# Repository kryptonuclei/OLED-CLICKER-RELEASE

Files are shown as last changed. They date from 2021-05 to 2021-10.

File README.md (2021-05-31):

# OLED-Clicker

This creation is designed to both be a fidget item while also being able to serve a purpose. It is an electronic counter and a fidget clicker utilizing mechanical keyboard switches. The OLED used is 1.3in across, larger than the typical horizontal OLEDs. The processor is an ATMEGA32U4, from an arduino leonardo framework. The code was developed in visual studio using arduino libraries. It is powered by an 18650 that is charged via a USB C connector. The 5V rail is connected to a TP4056 to handle the charging. The 32U4 is also connected to the USB C for programming.

A sleep mode is enabled after 1 minute of inactivity, during this mode, the clicker only draws 0.4mA, almost a year standby using a 3000mAh 18650!

There are some things that would be cool to integrate but have not been completed such as https://github.com/AlexIII/t-rex-duino and a selection of menus rather than the current mode toggles. The dino game has not yet been successfully integrated as it uses drivers which are written as part of the project, but this project uses an OLED that addresses with rows and columns swapped ie 64x128 rather than standard 128x64.

# Pictures



137523917_1570962459765296_4746547366832083114_n

# Model



# PCB




# Components

Link to OLED: https://www.aliexpress.com/item/1648493376.html?spm=a2g0s.9042311.0.0.50434c4dDTX8kw

| Part  | Value | Device | Description |
| ----- | --- | --- | --- |
| BT1 | | BATTERY-18650-Holder | Battery - Single Cell |
| C1 | 1u | C-EUC0603 | CAPACITOR, European symbol |
| C2 | 100n | C-EUC0603 | CAPACITOR, European symbol |
| C3 | 22p | C-EUC0603 | CAPACITOR, European symbol |
| C4 | 22p | C-EUC0603 | CAPACITOR, European symbol |
| C5 | 2.2u | C-EUC0603 | CAPACITOR, European symbol |
| C6 | 0.1u | C-EUC0603 | CAPACITOR, European symbol |
| C7 | 4.7u | C-EUC0603 | CAPACITOR, European symbol |
| C8 | 0.1u | C-EUC0603 | CAPACITOR, European symbol |
| C9 | 4.7u | C-EUC0603 | CAPACITOR, European symbol |
| C10 | 10u | C-EUC0805 | CAPACITOR, European symbol |
| C11 | 0.1u | C-EUC0603 | CAPACITOR, European symbol |
| C12 | 0.1u | C-EUC0603 | CAPACITOR, European symbol |
| C13 | 4.7p | C-EUC0603 | CAPACITOR, European symbol |
| C14 | 0.1u | C-EUC0603 | CAPACITOR, European symbol |
| D1 | | LED0603 | LED (Generic) |
| D2 | | LED0603 | LED (Generic) |
| D4 | | LED0603 | LED (Generic) |
| D5 | | LED0603 | LED (Generic) |
| D6 | | DIODE\_SOD-123FL | Diode |
| IC1 | DW01A | DW01A | Battery Protection |
| IC2 | TP4056 | TP4056 | Battery Charger |
| J1 | DX07S016JA1R1500 | DX07S016JA1R1500 | USB-C (USB TYPE-C) USB 2.0 Receptacle Connector 24 (16+8 Dummy) Position Surface Mount, Right Angle; Through Hole  |
| L1 | | L-EUL3225M | INDUCTOR, European symbol |
| OLED1 | ADAFRUIT\_DISPLAY\_OLED\_128X64\_SH1107 | ADAFRUIT\_DISPLAY\_OLED\_128X64\_SH1107 | Horizontal ribbon 1.3in OLED |
| Q1 | FS8205A | FS8205A | MOSFET |
| R1 | 22 | R-EU\_R0603 | RESISTOR, European symbol |
| R2 | 22 | R-EU\_R0603 | RESISTOR, European symbol |
| R3 | 10k | R-EU\_R0603 | RESISTOR, European symbol |
| R4 | 330 | R-EU\_R0603 | RESISTOR, European symbol |
| R5 | 330 | R-EU\_R0603 | RESISTOR, European symbol |
| R6 | 560k | R-EU\_R0603 | RESISTOR, European symbol |
| R7 | 4.7k | R-EU\_R0603 | RESISTOR, European symbol |
| R8 | 1k | R-EU\_R0603 | RESISTOR, European symbol |
| R9 | 1k | R-EU\_R0603 | RESISTOR, European symbol |
| R10 | 1k | R-EU\_R0603 | RESISTOR, European symbol |
| R11 | 1k | R-EU\_R0603 | RESISTOR, European symbol |
| R12 | 100 | R-EU\_R0603 | RESISTOR, European symbol |
| R13 | 4.7k | R-EU\_R0603 | RESISTOR, European symbol |
| R14 | 4.7k | R-EU\_R0603 | RESISTOR, European symbol |
| R15 | 1.43m | R-EU\_R0603 | RESISTOR, European symbol |
| R16 | 205k | R-EU\_R0603 | RESISTOR, European symbol |
| U$1 | ATMEGA32U4QFN2 | ATMEGA32U4QFN2 | Atmel 44-pin 8-bit Microcontroller with 32KBytes of ISP Flash and USB Controller ----- |
| U$2 | CHERRY-MX | CHERRY-MX | Cherry MX series keyswitch |
| U1 | TPS61040DBVR | TPS61040DBVR | Boost IC |
| Y1 | 16MHz | CRYSTAL-16MHZSMD-5X3.2 | 16MHz Crystal |

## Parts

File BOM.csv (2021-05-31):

Part | Value | Device | Package | Description
BT1 |  | BATTERY-18650 | BATTERY_18650-HOLDER | Battery - Single Cell
C1 | 1u | C-EUC0603 | C0603 | CAPACITOR, European symbol
C2 | 100n | C-EUC0603 | C0603 | CAPACITOR, European symbol
C3 | 22p | C-EUC0603 | C0603 | CAPACITOR, European symbol
C4 | 22p | C-EUC0603 | C0603 | CAPACITOR, European symbol
C5 | 2.2 | C-EUC0603 | C0603 | CAPACITOR, European symbol
C6 | 0.1 | C-EUC0603 | C0603 | CAPACITOR, European symbol
C7 | 4.7 | C-EUC0603 | C0603 | CAPACITOR, European symbol
C8 | 0.1 | C-EUC0603 | C0603 | CAPACITOR, European symbol
C9 | 4.7 | C-EUC0603 | C0603 | CAPACITOR, European symbol
C10 | 10u | C-EUC0805 | C0805 | CAPACITOR, European symbol
C11 | 0.1 | C-EUC0603 | C0603 | CAPACITOR, European symbol
C12 | 0.1 | C-EUC0603 | C0603 | CAPACITOR, European symbol
C13 | 4.7p | C-EUC0603 | C0603 | CAPACITOR, European symbol
C14 | 0.1u | C-EUC0603 | C0603 | CAPACITOR, European symbol
D1 |  | LED0603 | LED-0603 | LED (Generic)
D2 |  | LED0603 | LED-0603 | LED (Generic)
D4 |  | LED0603 | LED-0603 | LED (Generic)
D5 |  | LED0603 | LED-0603 | LED (Generic)
D6 |  | DIODE_SOD-123FL | SOD-123FL | Diode
IC1 | DW01A | DW01A | SOT23-6
IC2 | TP4056 | TP4056 | SOP-8
J1 | DX07S016JA1R1500 | DX07S016JA1R1500 | JAE_DX07S016JA1R1500 | USB-C (USB TYPE-C) USB 2.0 Receptacle Connector 24 (16+8 Dummy) Position Surface Mount, Right Angle; Through Hole Check prices
L1 |  | L-EUL3225M | L3225M | INDUCTOR, European symbol
OLED1 | ADAFRUIT_DISPLAY_OLED_128X64_SH1107 | ADAFRUIT_DISPLAY_OLED_128X64_SH1107 | ADAFRUIT_DISPLAY_QT1107P11A
PAD1 |  | SMD5 | SMD2,54-5,08 | SMD PAD
PAD2 |  | SMD5 | SMD2,54-5,08 | SMD PAD
PAD3 |  | SMD5 | SMD2,54-5,08 | SMD PAD
PAD4 |  | SMD5 | SMD2,54-5,08 | SMD PAD
Q1 | FS8205A | FS8205A | SOP65P640X120-8N | N/A
R1 | 22 | R-EU_R0603 | R0603 | RESISTOR, European symbol
R2 | 22 | R-EU_R0603 | R0603 | RESISTOR, European symbol
R3 | 10k | R-EU_R0603 | R0603 | RESISTOR, European symbol
R4 | 330 | R-EU_R0603 | R0603 | RESISTOR, European symbol
R5 | 330 | R-EU_R0603 | R0603 | RESISTOR, European symbol
R6 | 560k | R-EU_R0603 | R0603 | RESISTOR, European symbol
R7 | 4.7k | R-EU_R0603 | R0603 | RESISTOR, European symbol
R8 | 1k | R-EU_R0603 | R0603 | RESISTOR, European symbol
R9 | 1k | R-EU_R0603 | R0603 | RESISTOR, European symbol
R10 | 1k | R-EU_R0603 | R0603 | RESISTOR, European symbol
R11 | 1k | R-EU_R0603 | R0603 | RESISTOR, European symbol
R12 | 100 | R-EU_R0603 | R0603 | RESISTOR, European symbol
R13 | 4.7k | R-EU_R0603 | R0603 | RESISTOR, European symbol
R14 | 4.7k | R-EU_R0603 | R0603 | RESISTOR, European symbol
R15 | 1.43m | R-EU_R0603 | R0603 | RESISTOR, European symbol
R16 | 205k | R-EU_R0603 | R0603 | RESISTOR, European symbol
U$1 | ATMEGA32U4QFN2 | ATMEGA32U4QFN2 | SPARKFUN-DIGITALIC_QFN-44-NOPAD | Atmel 44-pin 8-bit Microcontroller with 32KBytes of ISP Flash and USB Controller -----
U$2 | CHERRY-MX | CHERRY-MX | CHERRY-MX | Cherry MX series keyswitch
U1 | TPS61040DBVR | TPS61040DBVR | SOT95P280X145-5N | Check prices
Y1 | 16MHz | CRYSTAL-16MHZSMD-5X3.2 | CRYSTAL-SMD-5X3.2-4PAD | 16MHz Crystal

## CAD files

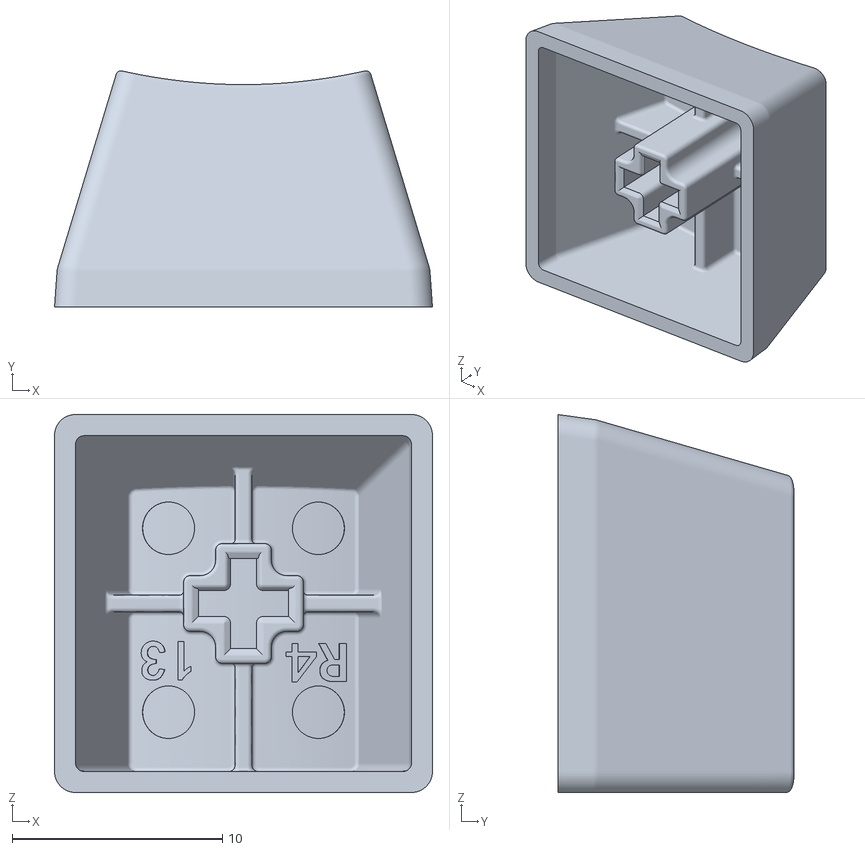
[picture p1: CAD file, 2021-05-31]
STL/keycap.stl
18.0 x 11.3 x 18.0

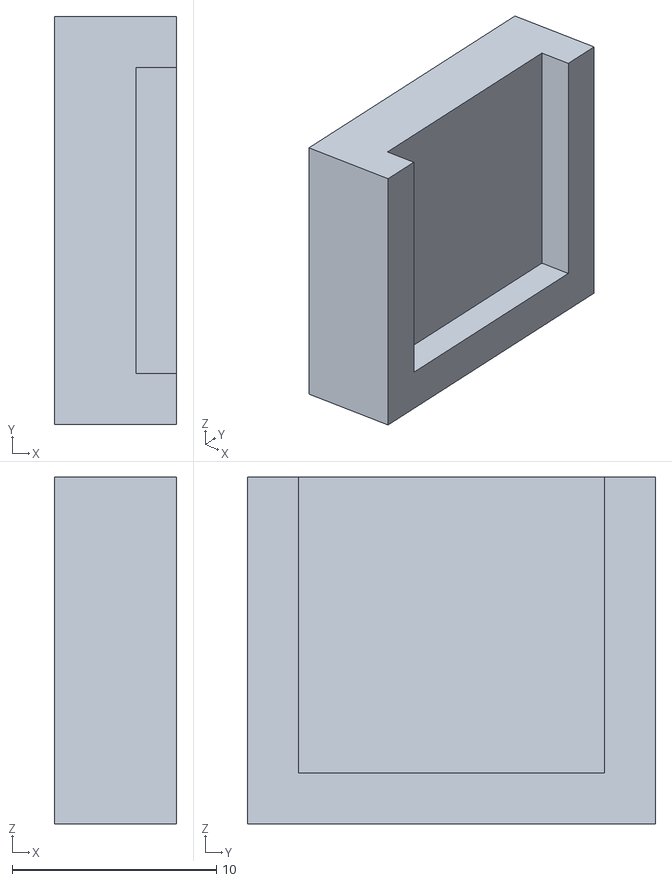
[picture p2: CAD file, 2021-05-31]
STL/spacer.stl
6.00 x 20.0 x 17.0

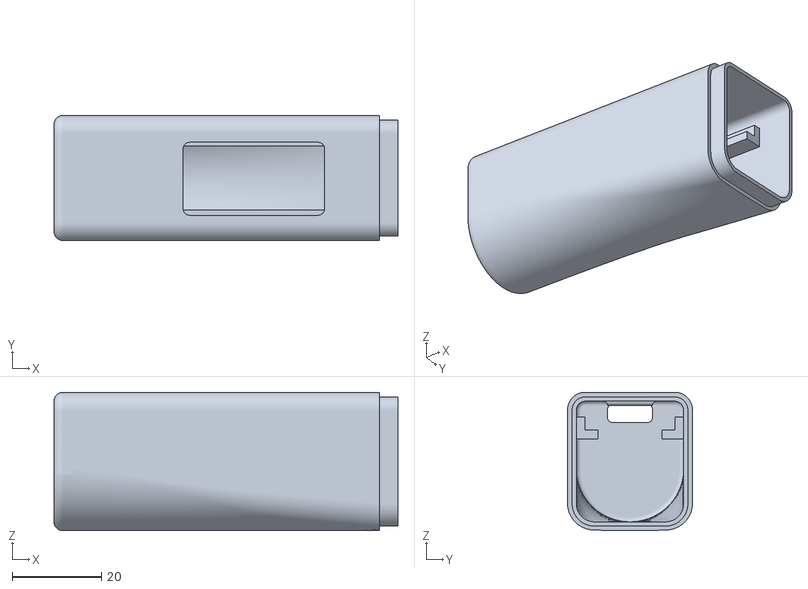
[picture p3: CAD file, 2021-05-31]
STL/bottom.stl
77.0 x 28.1 x 31.0

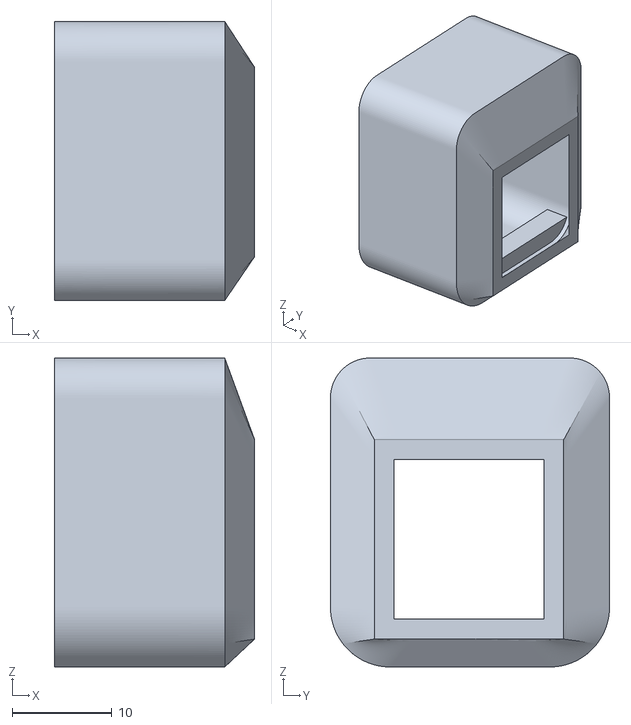
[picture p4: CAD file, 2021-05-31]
STL/top.stl
20.1 x 28.0 x 31.0

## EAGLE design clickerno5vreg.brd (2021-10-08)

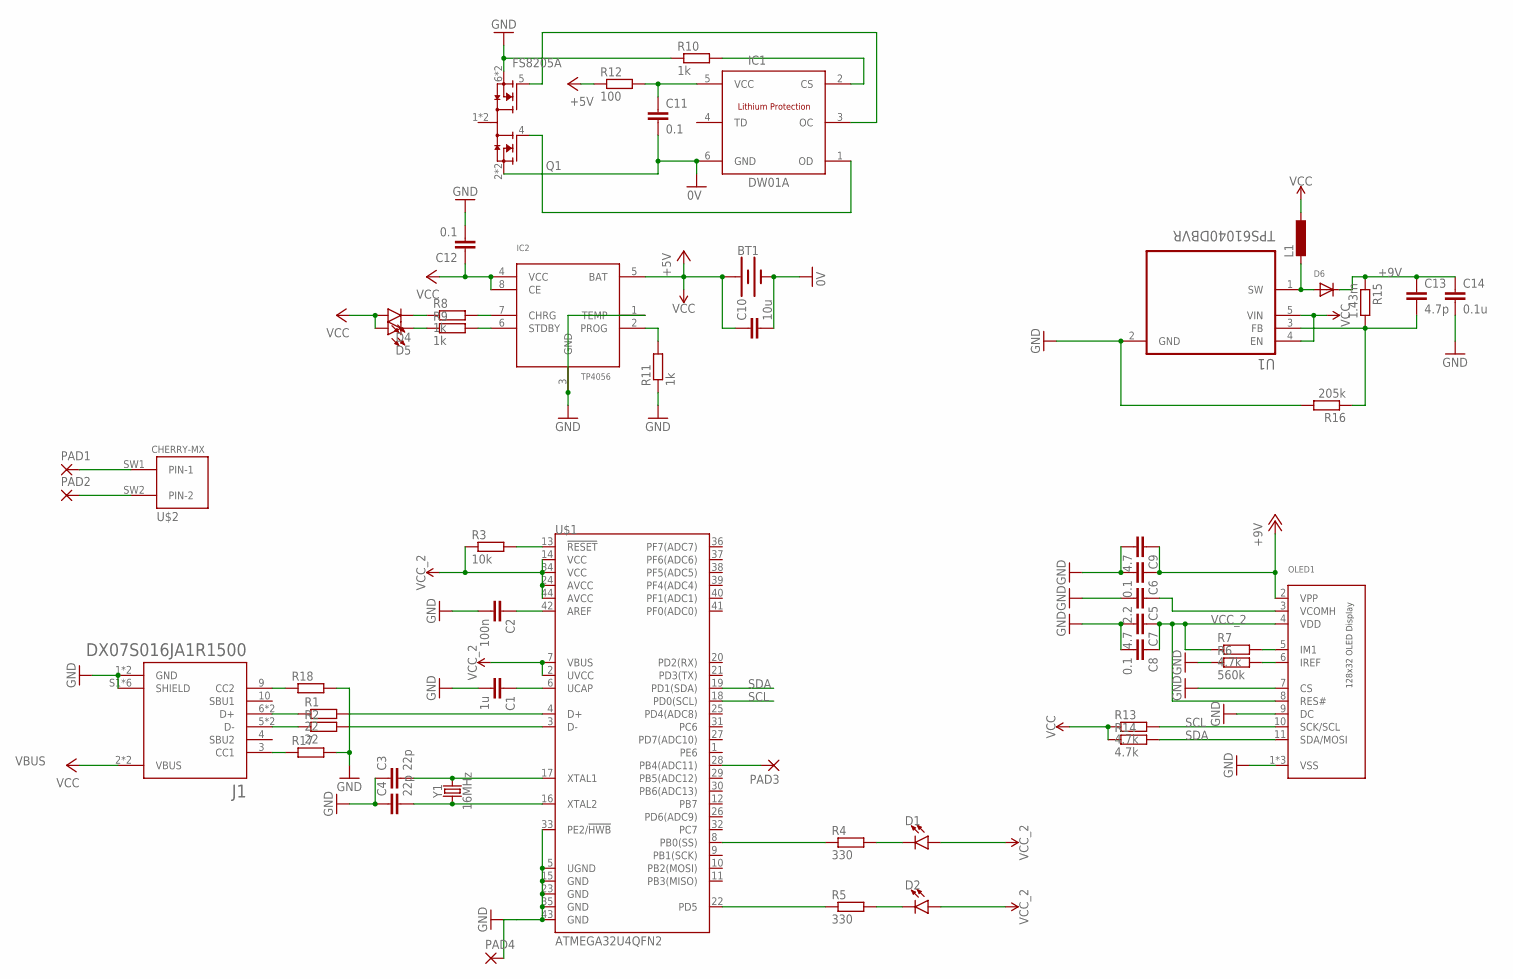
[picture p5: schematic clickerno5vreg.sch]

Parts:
BT1: BATTERY-18650; BATTERY_18650-HOLDER
C1: 1u; C0603
C2: 100n; C0603
C3, C4: 22p; C0603
C5: 2.2; C0603
C6, C8, C11, C12: 0.1; C0603
C7, C9: 4.7; C0603
C10: 10u; C0805
C13: 4.7p; C0603
C14: 0.1u; C0603
D1, D2, D4, D5: LED0603; LED-0603
D6: DIODE_SOD-123FL; SOD-123FL
IC1: DW01A; SOT23-6
IC2: TP4056; SOP-8
J1: DX07S016JA1R1500; JAE_DX07S016JA1R1500
L1: L-EUL3225M; L3225M
OLED1: ADAFRUIT_DISPLAY_OLED_128X64_SH1107; ADAFRUIT_DISPLAY_QT1107P11A
PAD1, PAD2, PAD3, PAD4: SMD5; SMD2,54-5,08
Q1: FS8205A; SOP65P640X120-8N
R1, R2: 22; R0603
R3: 10k; R0603
R4, R5: 330; R0603
R6: 560k; R0603
R7, R13, R14: 4.7k; R0603
R8, R9, R10, R11: 1k; R0603
R12: 100; R0603
R15: 1.43m; R0603
R16: 205k; R0603
R17, R18: R-EU_R0603; R0603
U1: TPS61040DBVR; SOT95P280X145-5N
U$1: ATMEGA32U4QFN2; SPARKFUN-DIGITALIC_QFN-44-NOPAD
U$2: CHERRY-MX
Y1: 16MHz; CRYSTAL-SMD-5X3.2-4PAD

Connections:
0V: BT1.GND@1 (-), C10.2, C11.2, IC1.6 (GND), Q1.2 (2,3), Q1.3 (2,3)
+9V: C6.1, C9.1, C13.1, C14.1, D6.C, OLED1.2 (VPP), R15.1
GND: C1.2, C2.2, C3.1, C4.1, C5.2, C6.2, C7.2, C8.2, C9.2, C12.2, C14.2, IC2.1 (TEMP), IC2.3 (GND), J1.1 (GND), J1.12 (GND), J1.S1 (SHIELD), J1.S2 (SHIELD), J1.S3 (SHIELD), J1.S4 (SHIELD), J1.S5 (SHIELD), J1.S6 (SHIELD), OLED1.1 (VSS), OLED1.7 (CS), OLED1.9 (DC), OLED1.12 (VSS), OLED1.13 (VSS), PAD4.1, Q1.6 (6,7), Q1.7 (6,7), R6.1, R10.1, R11.1, R16.2, R17.2, R18.2, U1.2 (GND), U$1.5 (UGND), U$1.15 (GND), U$1.23 (GND), U$1.33 (PE2/!HWB), U$1.35 (GND), U$1.43 (GND)
unnamed: C1.1, U$1.6 (UCAP)
unnamed: C2.1, U$1.42 (AREF)
unnamed: J1.6 (D+), J1.8 (D+), R1.1
unnamed: J1.5 (D-), J1.7 (D-), R2.1
unnamed: R1.2, U$1.4 (D+)
unnamed: R2.2, U$1.3 (D-)
unnamed: C4.2, U$1.16 (XTAL2), Y1.1
unnamed: C3.2, U$1.17 (XTAL1), Y1.3 (2)
unnamed: IC2.6 (STDBY), R9.2
unnamed: R3.2, U$1.13 (!RESET)
unnamed: R5.1, U$1.22 (PD5)
unnamed: R4.1, U$1.8 (PB0(SS))
unnamed: D1.C, R4.2
unnamed: D2.C, R5.2
unnamed: C5.1, OLED1.3 (VCOMH)
unnamed: C13.2, R15.2, R16.1, U1.3 (FB)
unnamed: OLED1.5 (IM1), R7.2
unnamed: IC1.1 (OD), Q1.4
unnamed: OLED1.6 (IREF), R6.2
unnamed: IC2.7 (CHRG), R8.2
unnamed: IC1.3 (OC), Q1.5
unnamed: C11.1, IC1.5 (VCC), R12.2
unnamed: D5.C, R9.1
unnamed: D4.C, R8.1
unnamed: IC2.2 (PROG), R11.2
unnamed: IC1.2 (CS), R10.2
unnamed: D6.A, L1.2, U1.1 (SW)
unnamed: PAD3.1, U$1.28 (PB4(ADC11))
unnamed: PAD2.1, U$2.SW2 (PIN-2)
unnamed: PAD1.1, U$2.SW1 (PIN-1)
unnamed: J1.3 (CC1), R17.1
unnamed: J1.9 (CC2), R18.1
SCL: OLED1.10 (SCK/SCL), R13.2, U$1.18 (PD0(SCL))
SDA: OLED1.11 (SDA/MOSI), R14.2, U$1.19 (PD1(SDA))
VBUS: C12.1, D4.A, D5.A, IC2.4 (VCC), IC2.8 (CE), J1.2 (VBUS), J1.11 (VBUS)
VCC_2: BT1.PWR@1 (+), C7.1, C8.1, C10.1, D1.A, D2.A, IC2.5 (BAT), L1.1, OLED1.4 (VDD), OLED1.8 (RES#), R3.1, R7.1, R12.1, R13.1, R14.1, U1.4 (EN), U1.5 (VIN), U$1.2 (UVCC), U$1.7 (VBUS), U$1.14 (VCC), U$1.24 (AVCC), U$1.34 (VCC), U$1.44 (AVCC)

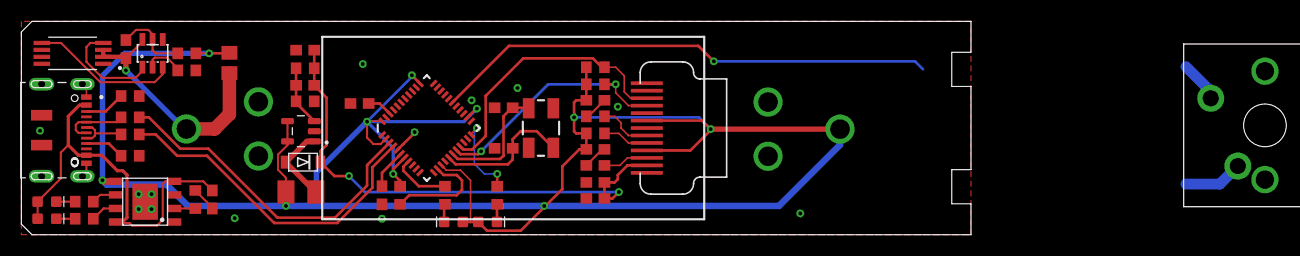
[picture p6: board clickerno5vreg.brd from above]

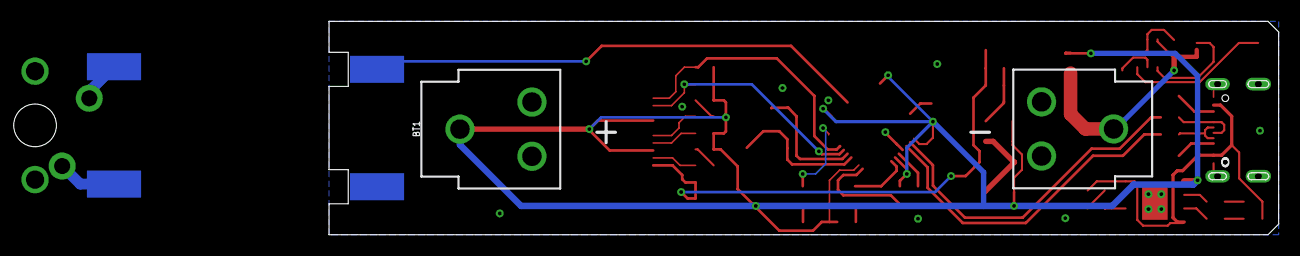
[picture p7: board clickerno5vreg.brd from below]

Board: 2 copper layers, 89.0 x 20.0 mm, 52 parts (5 on the bottom side), 39 nets.

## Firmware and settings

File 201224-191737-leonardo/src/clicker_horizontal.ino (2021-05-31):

//Includes
#include "Vcc.h"
#include <avr/sleep.h>
#include <Wire.h>
#include <Adafruit_GFX.h>
#include <Adafruit_SH110X.h>
Adafruit_SH110X display = Adafruit_SH110X(64, 128, &Wire);
const int buttonPin = 8;

//Maths
const float VccMin   = 2.7;           // Minimum expected Vcc level, in Volts.
const float VccMax   = 4.2;           // Maximum expected Vcc level, in Volts.
const float VccCorrection = 1.0/1.0;  // Measured Vcc by multimeter divided by reported Vcc (default is 1:1 ratio)
Vcc vcc(VccCorrection);
int clicks=0;
int clickst=0;
float clkmaf=0;
float cps=0;


//Timers
const unsigned long debounceInterval = 10;
const unsigned long modechange = 1000;
const unsigned long returnInterval = 2500;
const unsigned long sleepwait = 60000;
const unsigned long clicktimer = 10000;
unsigned long timeset = 0;
unsigned long timeleft = 0;
unsigned long buttonDownMillis = 0;
unsigned long lastPressMillis = 0;

//Logic
bool buttonState = true;
bool returnButtonState = false;
bool buttonlongpress=false;
bool justreset=false; //for ignoring button release upon reset
bool start=false; //for game start detection
bool gamerunning=false; 
bool gmjstrun=false; //game just run>>>>>fixes bug where sleep is called on game finish
bool slpskp=false; //sleep skip>>>>>fixes sleep bug
bool scrchg=false;//screen change
int screen = 1;


void displayturnon(){
  display.begin(0x3C, true); // Address 0x3C default
  display.clearDisplay();
  display.display();
  display.setRotation(1);
  display.setTextSize(2);
  display.setTextColor(SH110X_WHITE);
  display.setCursor(0,0);
}

void wake(){
}
void enableButtonInterrupt(void){
  // Enable pin change interrupt mask for pin PB4.
  PCMSK0 |= (1 << PCINT4);
  // Enable global pin change interrupts
  PCICR |= (1 << PCIE0);
  // Clear the Pin Change Interrupt flag
  PCIFR |= (1 << PCIF0);
}
// INTERRUPT VECTOR FOR PIN CHANGE INTERRUPTS (non-discriminate, but only PB4 pin change is enabled as a source).
  ISR(PCINT0_vect)
{
    // Perform wake routine
    wake();
    // Clear the Pin Change Interrupt flag (not sure if necessary)
    PCIFR |= (1 << PCIF0);
}

void toSleep(){
  set_sleep_mode(SLEEP_MODE_PWR_DOWN); 
  sleep_enable();
  // Enable external interrupt on PB4
  enableButtonInterrupt();
  sleep_mode();
  sleep_disable(); 
  displayturnon();
  lastPressMillis=millis();
}


void pressed() {
   
  if (buttonlongpress==false&&justreset==false&&scrchg==false){
    lastPressMillis=millis();
    clicks++;
    slpskp=true;
    if (screen==2&&clicks==1){
      start=true;
    }
  }

  justreset=false;
  if (buttonlongpress==true){
    buttonlongpress=false;
    clicks=0;
    clickst=0;
    clkmaf=0;
    justreset=true;
    display.clearDisplay();
    display.setCursor(5,20);
    display.print("RESETTING!");
    display.display();
    delay(500);
    
  }
  
}

void screenchange(){
      if(scrchg==true){
        switch(screen){
      
        case 1:
          screen=2;
          clicks=0;
          clickst=0;
          break;
        
        case 2:
          screen=1;
          clicks=0;
          clickst=0;
          break;
        }
        scrchg=false;
        justreset=true;
 }
}

void readVcc() {
  float v = vcc.Read_Volts();
  //float p = vcc.Read_Perc(VccMin, VccMax);
  display.setTextSize(1);
  display.setCursor(0,0);
  display.print("Voltage: ");
  display.setCursor(50,0);
  display.print(v);
  display.display();
  display.setTextSize(2);
  if(v>(VccMax+0.1)){
    display.setCursor(0,7);
    display.print("OVERCHARGED!");
    display.display();
  }
  if(v<VccMin){
    display.setCursor(0,7);
    display.print("LOW BATTERY!");
    display.display();
  }

}

void counterscreen(){
  display.clearDisplay();
  display.setCursor(35,15);
  display.print("Count:");
  display.setCursor(45,40);
  display.print(clicks);
  readVcc();
  display.display();
}

void timerscreen(){
  gmjstrun=false;
  unsigned long currentMillist = millis();
  display.setTextSize(1);
  if (clicks==0){
    display.clearDisplay();
    display.setCursor(8,25);
    display.print("Click Speed Counter");
    display.setCursor(20,40);
    display.print("Click to start");
    readVcc();
    display.display();
  }
  if (gamerunning==false&&clickst>0){
    display.clearDisplay();
    display.setCursor(15,15);
    display.print("Total clicks: ");
    display.print(clickst);
    display.setCursor(10,30);
    cps=(clkmaf/10);
    display.print("Clicks per Second: ");
    display.setCursor(50,45);
    display.print(cps);
    readVcc();
    display.display();
}
  
    if (clicks==1&&start==true&&justreset==false&&scrchg==false){
      display.clearDisplay();
      display.setCursor(25,25);
      display.print("Starting in 3");
      display.display();
      delay(500);
      display.clearDisplay();
      display.setCursor(25,25);
      display.print("Starting in 2");
      display.display();
      delay(500);
      display.clearDisplay();
      display.setCursor(25,25);
      display.print("Starting in 1");
      display.display();
      delay(500);
      start=false;
      gamerunning=true;
      timeset=currentMillist+clicktimer;
    }
 

  while (gamerunning==true){
    unsigned long currentMillist = millis();
  static unsigned long previousMillist = 0;
    timeleft = (-(currentMillist-timeset));
    display.clearDisplay();
    display.setCursor(25,20);
    display.print("Time Left:");
    display.print(timeleft);
    display.setCursor(25,30);
    display.print("Total clicks:");
    display.setCursor(60,40);
    display.print(clickst);
    display.display();
  if (currentMillist - previousMillist >= debounceInterval) {
    previousMillist = currentMillist;
    if (digitalRead(buttonPin) != buttonState) {
      buttonState = !buttonState;
      if (buttonState) {
        returnButtonState = false;
        clickst++;
        clicks++;
        clkmaf++;
      }
    }
  }
  if (timeleft>0&&timeleft<100){
    gamerunning=false;
    gmjstrun=true;
  }
  }
  if(clicks==1){
    clicks=0;
  }

}


void setup(){
  pinMode(buttonPin, INPUT_PULLUP);
  pinMode(7, INPUT_PULLUP);
  displayturnon();
  display.clearDisplay();
  display.setCursor(50,10);
  display.print("Ze");
  display.setCursor(20,35);
  display.print("Clicker");
  display.display();
  delay(500);
}

void loop(){
  
  unsigned long currentMillis = millis();
  static unsigned long previousMillis = 0;
  slpskp=false;

  

    if (screen==1&&scrchg==false){
      counterscreen();
    }
    if (screen==2&&scrchg==false){
      timerscreen();
    
    }
  



//short press
  if (currentMillis - previousMillis >= debounceInterval) {
    previousMillis = currentMillis;
    if (digitalRead(buttonPin) != buttonState) {
      buttonState = !buttonState;
      if (buttonState) {
        returnButtonState = false;
        pressed();
        screenchange();
        justreset=false;
      }
      else {
        buttonDownMillis = currentMillis;
        returnButtonState = true;
        
      }
    }
    // Check long press
    else if (returnButtonState) {
      if(currentMillis - buttonDownMillis >= modechange && currentMillis - buttonDownMillis <=returnInterval) {
        scrchg=true;
        display.clearDisplay();
        display.setTextSize(1);
        display.setCursor(0,20);
        display.print("Release to change mode or keep holding for reset");
        display.display();
        display.setTextSize(2);
        
      }

      if (currentMillis - buttonDownMillis >=returnInterval) {
        scrchg=false;
        returnButtonState = false;
        buttonlongpress=true;
        pressed();
      }
    }
  }
  //sleep timer
  if (currentMillis - lastPressMillis >= sleepwait) {
    if(gmjstrun==false&&slpskp==false){
        display.oled_command(0xAE);
        toSleep();
      }
  }
    
 
}

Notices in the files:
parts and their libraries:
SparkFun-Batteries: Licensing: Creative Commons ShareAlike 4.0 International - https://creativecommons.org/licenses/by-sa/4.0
